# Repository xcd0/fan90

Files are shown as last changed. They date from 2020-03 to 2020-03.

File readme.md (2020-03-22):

# one hand keyboard fan

片手用キーボードです。G13のような用途を想定しています。  
左手で使うことを想定していますが、右手でも使えるようにPCBは作っています。  
流行りのミニマムなキーボードとは反対方向のマキシマムな方向のキーボードです。  
両手で使うことを想定していませんが、両面対応しているので2つ用意すれば可能です。  

初めての自作キーボードなので楽しみなのと不安なのが混在しています\_(:3 」∠ )\_
あくまで初めてつくる自作キーボードであるため、当然ながら動かない可能性が高いです。

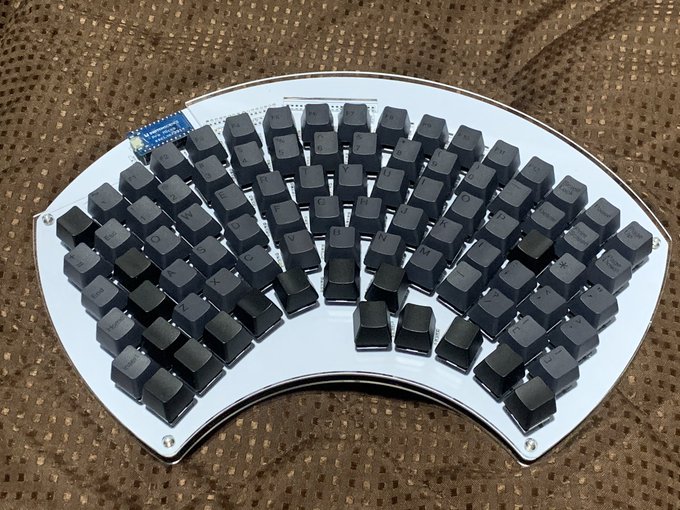
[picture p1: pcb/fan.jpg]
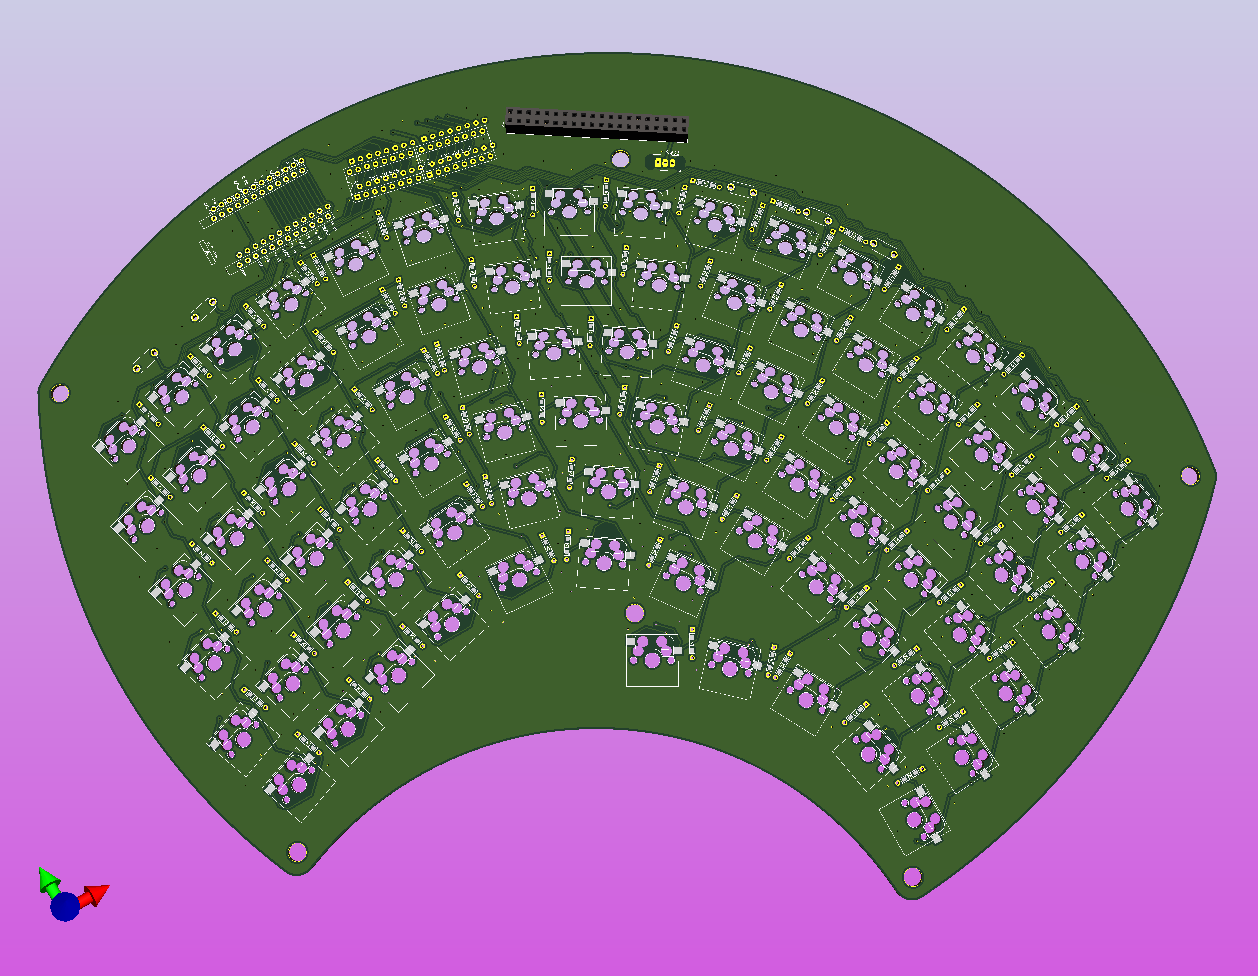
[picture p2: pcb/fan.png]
 
<details>
<summary>開発経緯</summary>

## キーボード割ろうとしたら曲がった
* ありものは素晴らしい、でも自分で作ってみたい。よし、初めてのキーボード自作だ！PCBから作るぞ\\('ω')/
* 今使ってるhelixよい。でもErgodox的な縦のずれがあるキーボードもよさそう。そういうの作ろう...
* 左右分割型のキーボード良い。割りたい！でも左右の通信とかどうやってるんだろう...ちゃんと作れるかな...
* とりあえずキーを並べてみる。小指とか根元に近く配置しよう...
* 見た目汚いな...とりあえずきれいに並べてみるか...あれ、なんか曲がってきた...
* あれこれ片手でフルキーボードいけるんじゃ...

という感じでした\_(:3 」∠ )\_  
つまりキーボードを割ろうとしたが、  
筋力が足りなかったため（左右に分割したときの左右間の通信を電源(VCC,GND)と信号線の3本でどうやって通信してるのかわからなかったので）、  
割れずに曲がってしまった。  
次作るときは割りたい。  
名前は見た目がうちわのようになったため。  もちろん余った基板は重めの団扇として使うことができる。
鍋敷きにしてもよい。
</details>

<details>
<summary>構想</summary>

### コンセプト
以下で東西南北を言うときは、左手で中指の方向を北とした場合の手のひらからの方向を指します。

* 片手でたくさんのキーを使える。
	* フルキーボード相当のキーを使えるものとする。
		* 現状6x15のマトリクスで87キーを配置。
		* 残り３キーはあまり使わない用途向けにリセットスイッチ部品で配置。

* 片手で使いやすい。
	* 指毎の特徴に合わせて配置する。  
		例えば
		* 親指はゲームのコントローラーで多用されるように本来非常に性能が良い。  
		しかしキーボードを使う上で親指を生かすのは難しい。  
		Twitterの投票によると親指に複数のキーを割り当てているときに使っているキーの数はせいぜい4キーらしい。  
		このキーボードでは多めに5キーを割り当てる。
		* 人差し指は性能が良くQWERTYでもほかの指より多いキーを担当する。  
		このキーボードでも人差し指の担当は多くする。
		* 中指は人差し指と同じくらいのせいのがある。中指にも多めのキーを割り当てる。
		* 薬指は中指と一緒に動かないと性能が良くないので、キーボードではあまり性能を発揮できない。
		ただし、北西方向は強く、北西方向に関しては小指より適している。。
		* 小指は短いので、北西方向の移動は難しい。  
		しかし西方向、南西方向はそこそこ性能が良い。
	* 指に合わせてキーを配置する。
		* 変則的な配置なので指１本に対して割り当てられたキーの数は様々。
			* 現状小指20、薬指15、中指12、人差し指31、親指5キー。人差し指と小指は無駄キーを含む。足しても90にはならない。
		* 将来的にはキーを立体的に配置するのもよいが、現状は平面に配置。
	* 指は伸ばした状態のほうが押しやすく、キーを押し分けやすい。
		* 指の根本に近いキーよりも指を伸ばしたときに押すキーのほうが押しやすい。
		* 指の根元に近いキーを減らし、指を伸ばしたときに押すキーを増やす。
	* レイヤーは極力つかわない。
		* シフトキーのように押しながら操作することは片手だと難しい。

* すべてのキーを常に使うキーにはせず、使う用途に合わせてカスタマイズできるよう、無駄にキーを配置する。

### 実現方法

* 以下の2点からキーを扇状に配置する。
	* 小指の性能を発揮できるように小指のキーは手首側に寄せる。
	* 伸ばした状態で使える人差し指、中指のキーを増やす。
* 列方向には揃えず、行方向にはそろえる。
* 無駄にキーを小指の西側、人差し指の東側、すべての指の北側に配置する。つまり一回り大きくする。

### 将来的にやりたいこと

* QMKを使わずに作る。(現状使う)
* C以外の言語で作る。(現状C言語)
* マイコンを複数種類使えるようにする。(現状むずかしい)
* raspberry pi zeroと画面を搭載して、それ単体でPCとして動作させ多機能にする。(現状ソケットのみ用意)
* ケースを3Dプリンターなどでつくる。
* キーを立体的に配置する。

</details>

<details>
<summary>設計</summary>

## PCB設計

kicadを使って設計した。

回路は6x15のマトリクス。column方向からスキャンし、rowを検出する。  
column方向のスキャンは床に転がっていたSN74HC595を使う。  
シフトレジスタを使えば簡単にスキャンできそう。  
これで信号線数を15-5で10本減らせることになる。  
pro microはデジタルIOピンが14本、デジタルとしても使えるアナログIOピンが4本なので、
最大18本をデジタルIOとして使うことができる。
6本をrowのデジタル入力に、5本をシフトレジスタへのデジタル出力に、
2本をリセットスイッチに使用することにした。
配置は特にこだわりなく並べた。このせいで後々苦労するかもしれないがまあ初めてなので良しとする。

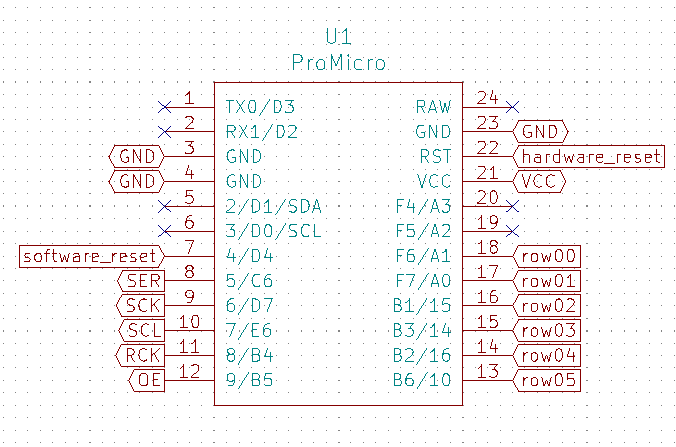
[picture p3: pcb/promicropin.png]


## アクリルケース設計

* ケースもとりあえずアクリルで作ることにした。
* ケースもDXFで入稿できるみたいなのでkicadでそのまま作った。
	* SVGでもよさそうだがそもそもSVGで線幅を狭くするとinkscapeやchromeで表示したとき線が描画されない問題があった。
* アクリルは[工房Emerge+](https://www.emergeplus.jp/laser-cutting-service/)を使ってみることにした。
	* elecrowはウェブサイトの調子が良くないのか、そもそもサービス中止中なのか、  
	https://twitter.com/xcd0/status/1233658167684296704  
	のようにfalseとなっていた。
	* 遊舎工房は、キーボードのサイズが大きいので元のアクリル板が最低でもA3より大きな必要があり、  
	A5,A4,450 X 300と、450x300以外の選択肢がなく、このサイズでも2枚発注する必要がある。  
	そして150x300程度の余白ができてしまう。
	* Emarge+は600x300に対応しており、これだと１枚に収まる。なのでここにしてみた。
	* 遊舎工房とEmerge+はillustratorありきの体制で、すごくストレスフルであった。
	* inkscapeは線幅の問題で使えず、外形と内形を色を変えるとかレイヤーを変えるとか言った操作はillustratorがないと難しいというか不可能な作業であった。
	* 今回５個ほどソフトを試したが、どれも満たせずあきらめてillustratorの7日間仕様版を使った。
	* 次回はaiやsvgではなくDXFで入稿したい。
	* elecrow復活してほしい... ← 復活してた
* データ蹴られるかと思ったがとりあえず通った。
* DXFもレイヤー分けていればよいらしい。

</details>

<details>
<summary>作成</summary>

## はんだ付け

[キースイッチを手軽に交換できる Kailh PCBソケット](https://talpkeyboard.stores.jp/items/5e02c5405b120c792616bcf9)
とダイオードをちまちまつけていく。

ダイオードの向きは今のシルクだと上向きになっているが、
本当は下向きが良い。
上向きだと正論理でキースキャンをする形になる。
それでいいと思っていたが、Pro Microは入力端子の内部抵抗がどうもプルアップにしかできないみたい。
今回はもうダイオードをつけてしまったのでPro Microの入力端子に10kΩの抵抗をつけてプルダウンした。
現状のプログラムはプルダウンした回路を前提にしている。
もし誰か同じものを作りたい人がいたら、回路を修正して内蔵プルアップ抵抗を使う負論理のキースキャンにプログラムを変更する方がよい。

ソケットは向きを考えて穴にはめていく。
はめた状態だとフットプリントが完全に隠れてしまうので、はんだを適当につけたら問題ない。
と思いきや、そうでもなくて、フットプリントとソケットが浮いていたりする...
めちゃもりもりはんだを盛った。

フットプリントを少し大きくした方が良いなとわかった。

## 組み立て

構造は簡単なので特に迷うことはないはず。

## プログラム作成

プログラムは適当にさっと作った。
[ここ](https://docs.qmk.fm/#/ja/custom_matrix)を参考にmatrix.cを追加して、matrix.cにシフトレジスタでキースキャンするプログラムを書いた。

上にも書いたが現状正論理で書いているので新しく作るときは負論理にしたほうがよい。

</details>

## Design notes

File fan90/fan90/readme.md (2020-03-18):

# fan90

* Pro Micro

| ピン | 名前 | 説明 | io  |
| ---  | --- | --- | --- |
| 1 | TX0/D3 | - | - |
| 2 | RX1/D2 | - | - |
| 3 | GND | GND | - |
| 4 | GND | GND | - |
| 5 | D2/ | - | - |
| 6 | D3/ | - | - |
| 7 | D4/ | software reset | i |
| 8 | D5/ | SER | o |
| 9 | D6/ | SCK | o |
| 10 | D7/ | SCL | o |
| 11 | D8/ | RCK | o |
| 12 | D9/ | OE | o |
| 13 | B6/10/D10  | row05 | i |
| 14 | B2/16/MOSI | row04 | i |
| 15 | B3/14/MISO | row03 | i |
| 16 | B1/15/SCK  | row02 | i |
| 17 | F7/A0 | row01 | i |
| 18 | F6/A1 | row00 | i |
| 19 | F5/A2 | - | - |
| 20 | F4/A3 | - | - |
| 21 | VCC | VCC | - |
| 22 | RESET | hardware reset | i |
| 23 | GND | GND | - |
| 24 | VCC | - | - |

* SN74HC595N

| ピン | 名前 | 入出力 | 説明 |
| --- | --- | --- | --- |
| 8 | GND | -– | グラウンド |
| 10 | SRCLR | 入力 | シフトレジスタのクリア |
| 11 | SRCLK | 入力 | シフトレジスタのクロック信号 |
| 12 | RCLK | 入力 | ストレージレジスタのクロック信号 |
| 13 | OE | 入力 | 出力の有効化 |
| 14 | SER | 入力 | シリアル入力 |
| 16 | Vcc | - | –電源 |
| 15,1〜7 | QA、QB〜QH | 出力 | パラレル出力 |
| 9 | QH’ | 出力 | シフトレジスタの最上位ビットの状態を常に出力 |

##

fan90

A short description of the keyboard/project

* Keyboard Maintainer: [xcd0](https://github.com/yourusername)
* Hardware Supported: The PCBs, controllers supported
* Hardware Availability: Links to where you can find this hardware

Make example for this keyboard (after setting up your build environment):

    make fan90:default

See the [build environment setup](https://docs.qmk.fm/#/getting_started_build_tools) and the [make instructions](https://docs.qmk.fm/#/getting_started_make_guide) for more information. Brand new to QMK? Start with our [Complete Newbs Guide](https://docs.qmk.fm/#/newbs).

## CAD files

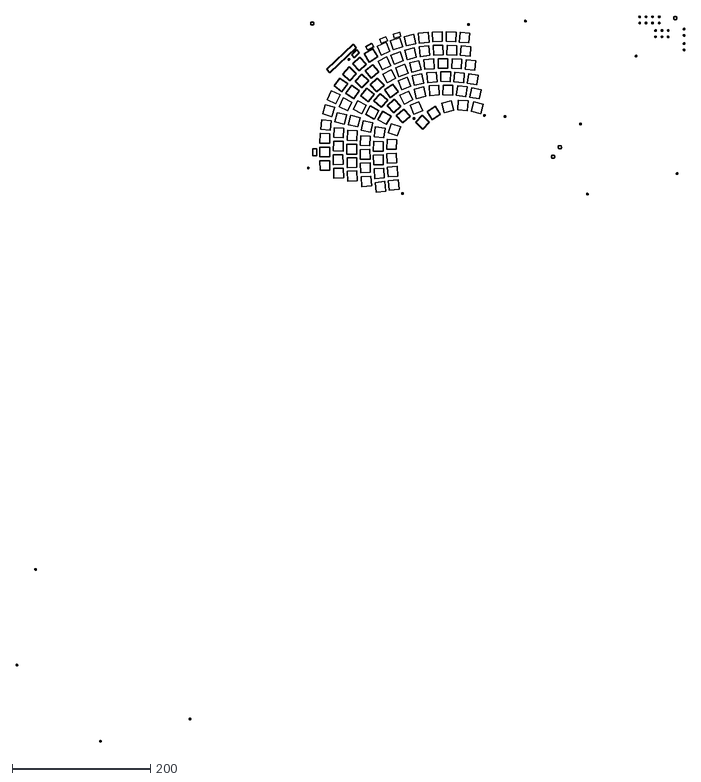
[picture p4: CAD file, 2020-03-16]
pcb/gbr/fan_1.24_300x600_inner.dxf
968.6 x 1051.5

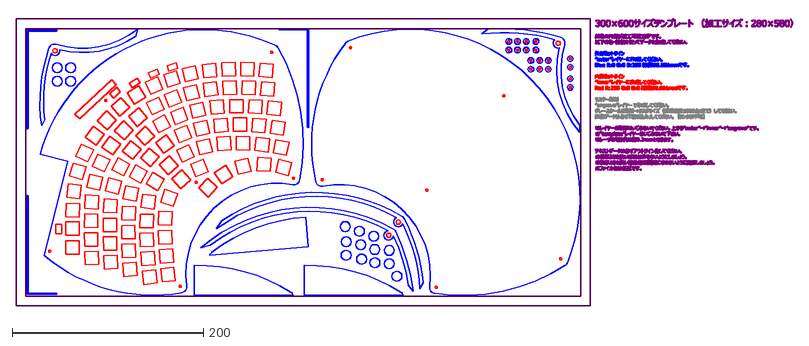
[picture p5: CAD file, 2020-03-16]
pcb/gbr/fan_1.25_300x600.dxf
811.8 x 303.0

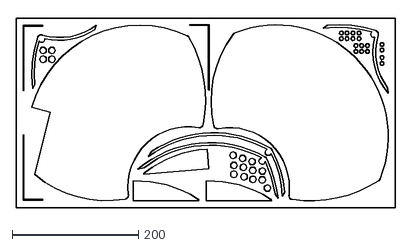
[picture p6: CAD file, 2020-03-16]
pcb/gbr/fan_1.24_300x600_outer.dxf
603.2 x 303.0

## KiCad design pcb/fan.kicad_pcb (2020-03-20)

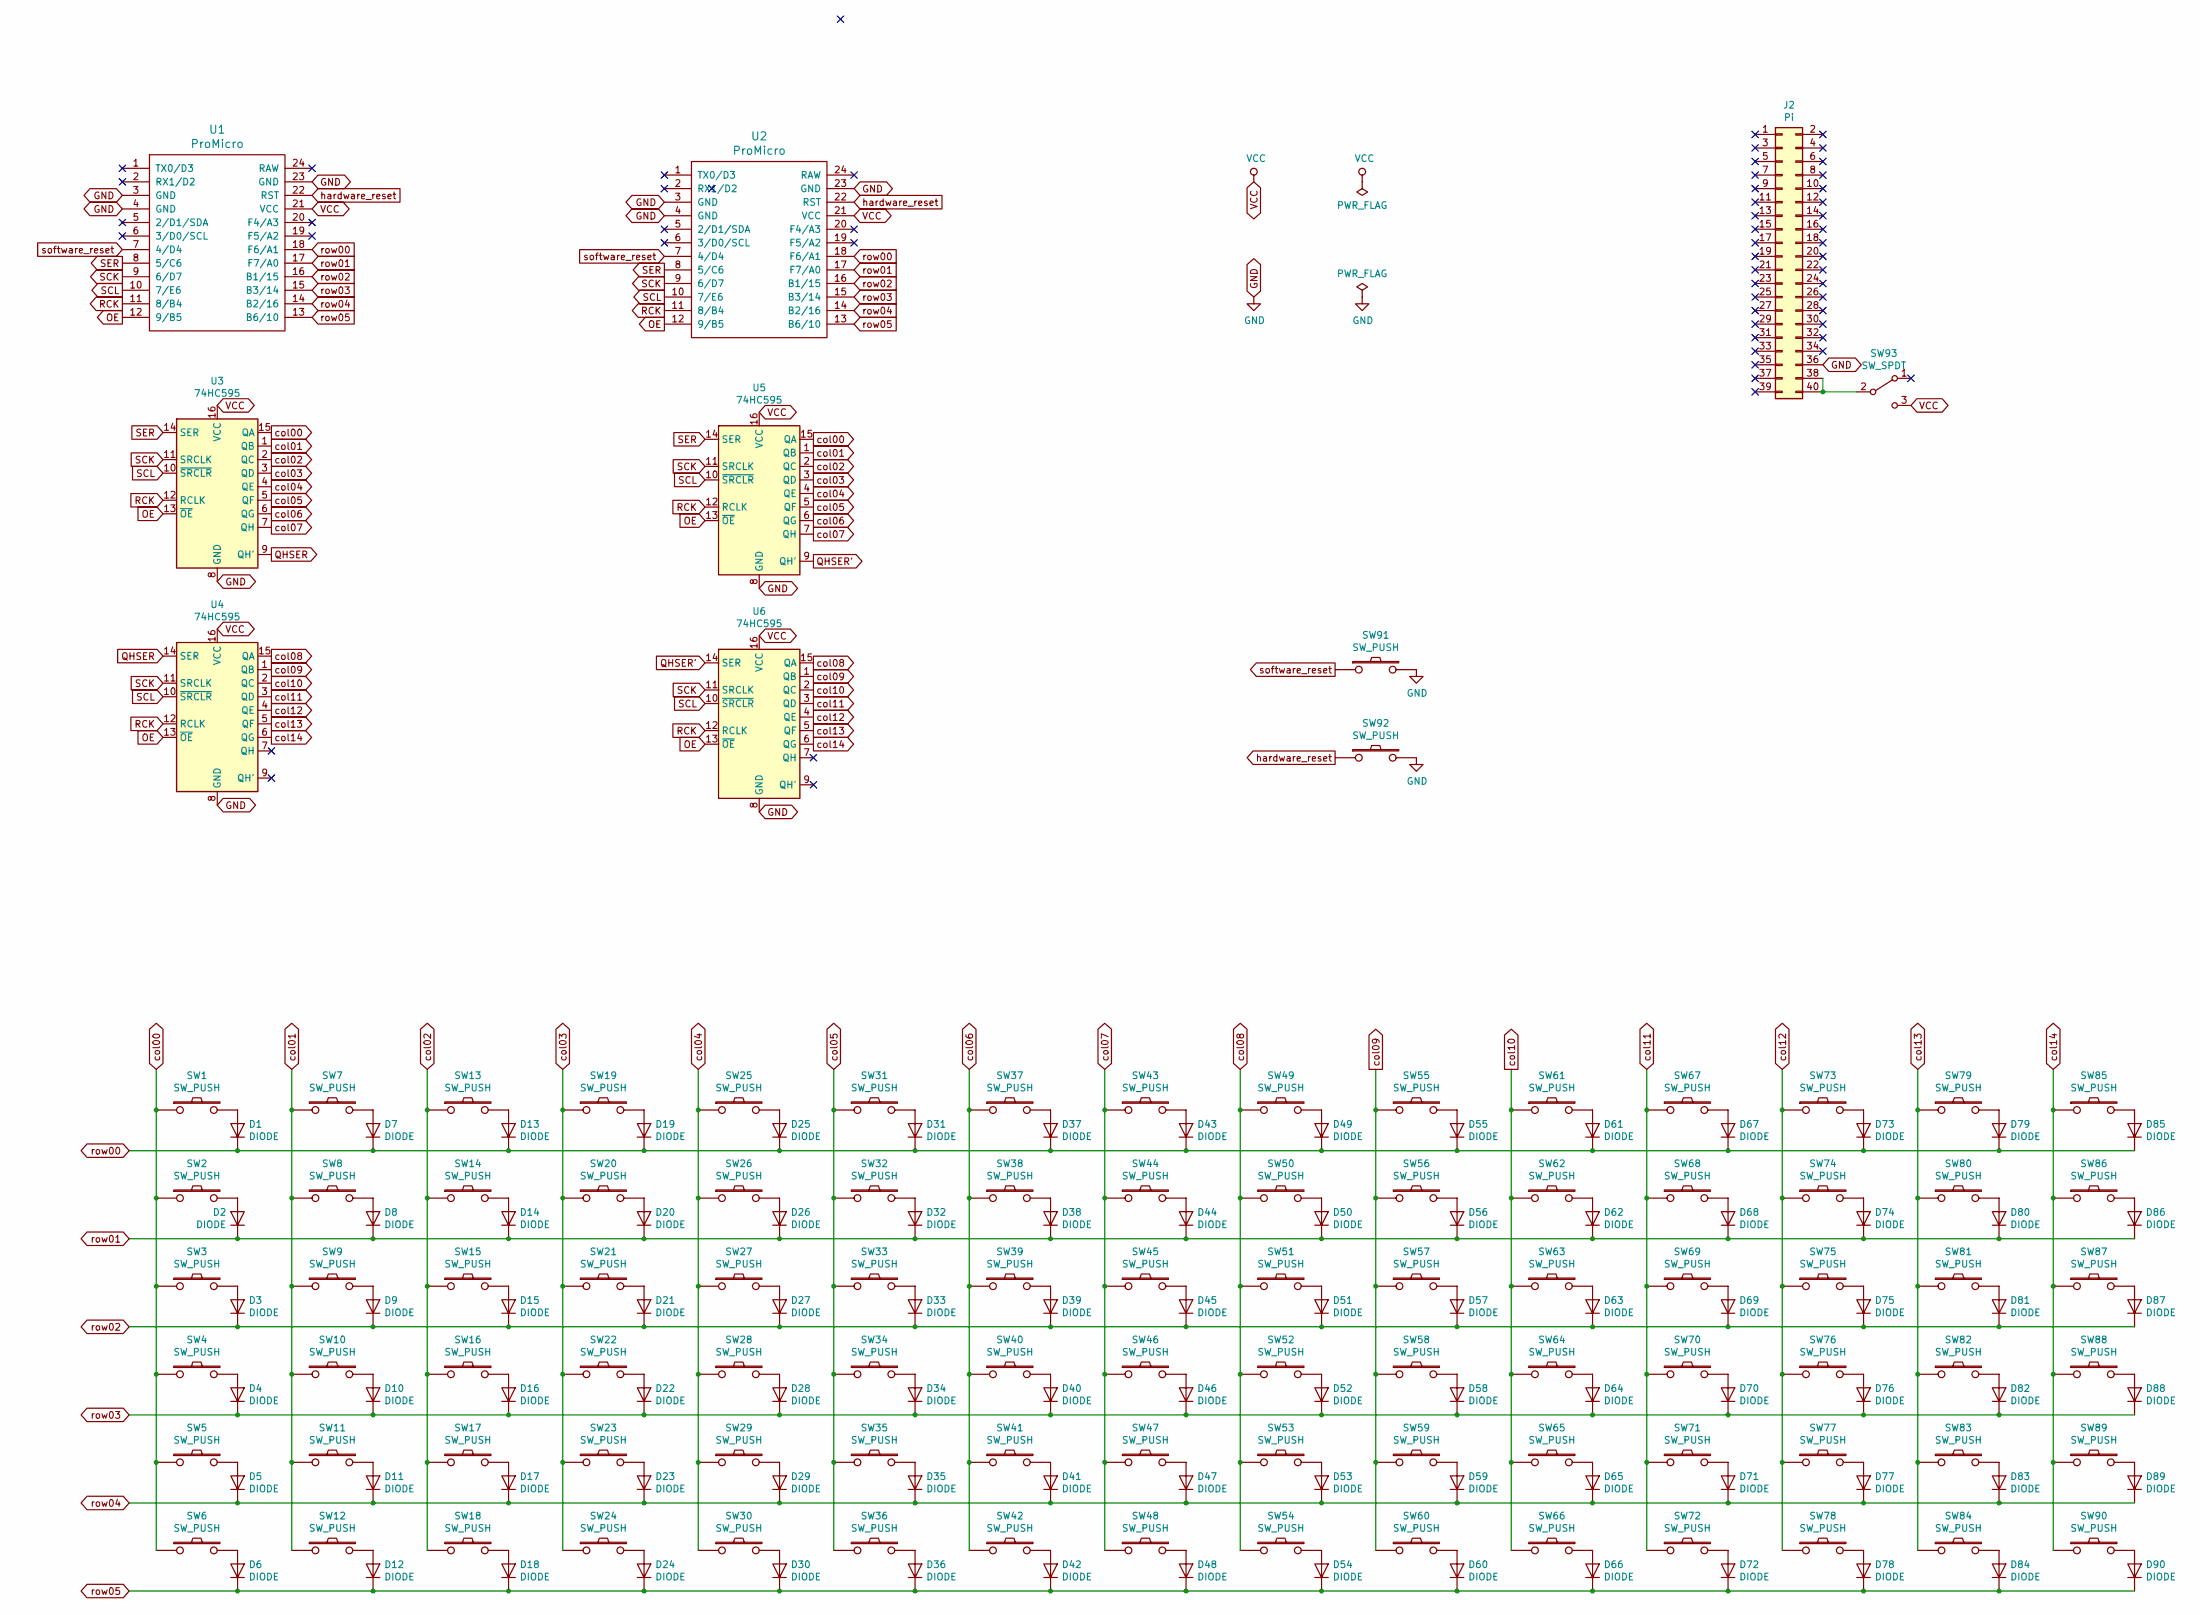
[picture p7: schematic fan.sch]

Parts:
D1, D2, D3, D4, D5, D6, D7, D8, D9, D10, D11, D12, D13, D14, D15, D16, D17, D18, D19, D20, D21, D22, D23, D24, D25, D26, D27, D28, D29, D30, D31, D32, D33, D34, D35, D36, D37, D38, D39, D40, D41, D42, D43, D44, D45, D46, D47, D48, D49, D50, D51, D52, D53, D54, D55, D56, D57, D58, D59, D60, D61, D62, D63, D64, D65, D66, D67, D68, D69, D70, D71, D72, D73, D74, D75, D76, D77, D78, D79, D80, D81, D82, D83, D84, D85, D86, D87, D88, D89, D90: DIODE; D3_TH_SMD
J2: Pi; PinSocket_2x20_P2.54mm_Vertical
SW1, SW2, SW3, SW4, SW5, SW6, SW7, SW8, SW9, SW10, SW11, SW12, SW13, SW14, SW15, SW16, SW17, SW18, SW19, SW20, SW21, SW22, SW23, SW24, SW25, SW26, SW27, SW28, SW29, SW30, SW31, SW32, SW33, SW34, SW35, SW36, SW37, SW38, SW39, SW40, SW41, SW42, SW43, SW44, SW45, SW46, SW47, SW48, SW51, SW52, SW53, SW54, SW56, SW57, SW58, SW59, SW60, SW61, SW62, SW63, SW64, SW65, SW66, SW67, SW68, SW69, SW70, SW71, SW72, SW73, SW74, SW75, SW76, SW77, SW78, SW79, SW80, SW81, SW82, SW83, SW84, SW85, SW86, SW87, SW88, SW89, SW90: SW_PUSH; CherryMX_Hotswap
SW49, SW50, SW55, SW91, SW92: SW_PUSH; ResetSW
SW93: SW_SPDT; SW_Slide_1P2T_CK_OS102011MS2Q
U1, U2: ProMicro; ProMicro_v3.6
U3, U4, U5, U6: 74HC595; SN74HC595_DIP-16_W7.62mm_Socket_2

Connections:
GND: J2.36, SW91.2, SW92.2, U1.3 (GND), U1.4 (GND), U1.23 (GND), U2.3 (GND), U2.4 (GND), U2.23 (GND), U3.8 (GND), U4.8 (GND), U5.8 (GND), U6.8 (GND)
unnamed: D1.2 (A), SW1.2
unnamed: D2.2 (A), SW2.2
unnamed: D3.2 (A), SW3.2
unnamed: D4.2 (A), SW4.2
unnamed: D5.2 (A), SW5.2
unnamed: D6.2 (A), SW6.2
unnamed: D7.2 (A), SW7.2
unnamed: D8.2 (A), SW8.2
unnamed: D9.2 (A), SW9.2
unnamed: D10.2 (A), SW10.2
unnamed: D11.2 (A), SW11.2
unnamed: D12.2 (A), SW12.2
unnamed: D13.2 (A), SW13.2
unnamed: D14.2 (A), SW14.2
unnamed: D15.2 (A), SW15.2
unnamed: D16.2 (A), SW16.2
unnamed: D17.2 (A), SW17.2
unnamed: D18.2 (A), SW18.2
unnamed: D19.2 (A), SW19.2
unnamed: D20.2 (A), SW20.2
unnamed: D21.2 (A), SW21.2
unnamed: D22.2 (A), SW22.2
unnamed: D23.2 (A), SW23.2
unnamed: D24.2 (A), SW24.2
unnamed: D25.2 (A), SW25.2
unnamed: D26.2 (A), SW26.2
unnamed: D27.2 (A), SW27.2
unnamed: D28.2 (A), SW28.2
unnamed: D29.2 (A), SW29.2
unnamed: D30.2 (A), SW30.2
unnamed: D31.2 (A), SW31.2
unnamed: D32.2 (A), SW32.2
unnamed: D33.2 (A), SW33.2
unnamed: D34.2 (A), SW34.2
unnamed: D35.2 (A), SW35.2
unnamed: D36.2 (A), SW36.2
unnamed: D37.2 (A), SW37.2
unnamed: D38.2 (A), SW38.2
unnamed: D39.2 (A), SW39.2
unnamed: D40.2 (A), SW40.2
unnamed: D41.2 (A), SW41.2
unnamed: D42.2 (A), SW42.2
unnamed: D43.2 (A), SW43.2
unnamed: D44.2 (A), SW44.2
unnamed: D45.2 (A), SW45.2
unnamed: D46.2 (A), SW46.2
unnamed: D47.2 (A), SW47.2
unnamed: D48.2 (A), SW48.2
unnamed: D49.2 (A), SW49.2
unnamed: D50.2 (A), SW50.2
unnamed: D51.2 (A), SW51.2
unnamed: D52.2 (A), SW52.2
unnamed: D53.2 (A), SW53.2
unnamed: D54.2 (A), SW54.2
unnamed: D55.2 (A), SW55.2
unnamed: D56.2 (A), SW56.2
unnamed: D57.2 (A), SW57.2
unnamed: D58.2 (A), SW58.2
unnamed: D59.2 (A), SW59.2
unnamed: D60.2 (A), SW60.2
unnamed: D61.2 (A), SW61.2
unnamed: D62.2 (A), SW62.2
unnamed: D63.2 (A), SW63.2
unnamed: D64.2 (A), SW64.2
unnamed: D65.2 (A), SW65.2
unnamed: D66.2 (A), SW66.2
unnamed: D67.2 (A), SW67.2
unnamed: D68.2 (A), SW68.2
unnamed: D69.2 (A), SW69.2
unnamed: D70.2 (A), SW70.2
unnamed: D71.2 (A), SW71.2
unnamed: D72.2 (A), SW72.2
unnamed: D73.2 (A), SW73.2
unnamed: D74.2 (A), SW74.2
unnamed: D75.2 (A), SW75.2
unnamed: D76.2 (A), SW76.2
unnamed: D77.2 (A), SW77.2
unnamed: D78.2 (A), SW78.2
unnamed: D79.2 (A), SW79.2
unnamed: D80.2 (A), SW80.2
unnamed: D81.2 (A), SW81.2
unnamed: D82.2 (A), SW82.2
unnamed: D83.2 (A), SW83.2
unnamed: D84.2 (A), SW84.2
unnamed: D85.2 (A), SW85.2
unnamed: D86.2 (A), SW86.2
unnamed: D87.2 (A), SW87.2
unnamed: D88.2 (A), SW88.2
unnamed: D89.2 (A), SW89.2
unnamed: D90.2 (A), SW90.2
unnamed: J2.38, J2.40, SW93.2 (B)
OE: U1.12 (9/B5), U2.12 (9/B5), U3.13 (~OE), U4.13 (~OE), U5.13 (~OE), U6.13 (~OE)
QHSER: U3.9 (QH'), U4.14 (SER)
QHSER': U5.9 (QH'), U6.14 (SER)
RCK: U1.11 (8/B4), U2.11 (8/B4), U3.12 (RCLK), U4.12 (RCLK), U5.12 (RCLK), U6.12 (RCLK)
SCK: U1.9 (6/D7), U2.9 (6/D7), U3.11 (SRCLK), U4.11 (SRCLK), U5.11 (SRCLK), U6.11 (SRCLK)
SCL: U1.10 (7/E6), U2.10 (7/E6), U3.10 (~SRCLR), U4.10 (~SRCLR), U5.10 (~SRCLR), U6.10 (~SRCLR)
SER: U1.8 (5/C6), U2.8 (5/C6), U3.14 (SER), U5.14 (SER)
VCC: SW93.3 (C), U1.21 (VCC), U2.21 (VCC), U3.16 (VCC), U4.16 (VCC), U5.16 (VCC), U6.16 (VCC)
col00: SW1.1, SW2.1, SW3.1, SW4.1, SW5.1, SW6.1, U3.15 (QA), U5.15 (QA)
col01: SW7.1, SW8.1, SW9.1, SW10.1, SW11.1, SW12.1, U3.1 (QB), U5.1 (QB)
col02: SW13.1, SW14.1, SW15.1, SW16.1, SW17.1, SW18.1, U3.2 (QC), U5.2 (QC)
col03: SW19.1, SW20.1, SW21.1, SW22.1, SW23.1, SW24.1, U3.3 (QD), U5.3 (QD)
col04: SW25.1, SW26.1, SW27.1, SW28.1, SW29.1, SW30.1, U3.4 (QE), U5.4 (QE)
col05: SW31.1, SW32.1, SW33.1, SW34.1, SW35.1, SW36.1, U3.5 (QF), U5.5 (QF)
col06: SW37.1, SW38.1, SW39.1, SW40.1, SW41.1, SW42.1, U3.6 (QG), U5.6 (QG)
col07: SW43.1, SW44.1, SW45.1, SW46.1, SW47.1, SW48.1, U3.7 (QH), U5.7 (QH)
col08: SW49.1, SW50.1, SW51.1, SW52.1, SW53.1, SW54.1, U4.15 (QA), U6.15 (QA)
col09: SW55.1, SW56.1, SW57.1, SW58.1, SW59.1, SW60.1, U4.1 (QB), U6.1 (QB)
col10: SW61.1, SW62.1, SW63.1, SW64.1, SW65.1, SW66.1, U4.2 (QC), U6.2 (QC)
col11: SW67.1, SW68.1, SW69.1, SW70.1, SW71.1, SW72.1, U4.3 (QD), U6.3 (QD)
col12: SW73.1, SW74.1, SW75.1, SW76.1, SW77.1, SW78.1, U4.4 (QE), U6.4 (QE)
col13: SW79.1, SW80.1, SW81.1, SW82.1, SW83.1, SW84.1, U4.5 (QF), U6.5 (QF)
col14: SW85.1, SW86.1, SW87.1, SW88.1, SW89.1, SW90.1, U4.6 (QG), U6.6 (QG)
hardware_reset: SW92.1, U1.22 (RST), U2.22 (RST)
row00: D1.1 (K), D7.1 (K), D13.1 (K), D19.1 (K), D25.1 (K), D31.1 (K), D37.1 (K), D43.1 (K), D49.1 (K), D55.1 (K), D61.1 (K), D67.1 (K), D73.1 (K), D79.1 (K), D85.1 (K), U1.18 (F6/A1), U2.18 (F6/A1)
row01: D2.1 (K), D8.1 (K), D14.1 (K), D20.1 (K), D26.1 (K), D32.1 (K), D38.1 (K), D44.1 (K), D50.1 (K), D56.1 (K), D62.1 (K), D68.1 (K), D74.1 (K), D80.1 (K), D86.1 (K), U1.17 (F7/A0), U2.17 (F7/A0)
row02: D3.1 (K), D9.1 (K), D15.1 (K), D21.1 (K), D27.1 (K), D33.1 (K), D39.1 (K), D45.1 (K), D51.1 (K), D57.1 (K), D63.1 (K), D69.1 (K), D75.1 (K), D81.1 (K), D87.1 (K), U1.16 (B1/15), U2.16 (B1/15)
row03: D4.1 (K), D10.1 (K), D16.1 (K), D22.1 (K), D28.1 (K), D34.1 (K), D40.1 (K), D46.1 (K), D52.1 (K), D58.1 (K), D64.1 (K), D70.1 (K), D76.1 (K), D82.1 (K), D88.1 (K), U1.15 (B3/14), U2.15 (B3/14)
row04: D5.1 (K), D11.1 (K), D17.1 (K), D23.1 (K), D29.1 (K), D35.1 (K), D41.1 (K), D47.1 (K), D53.1 (K), D59.1 (K), D65.1 (K), D71.1 (K), D77.1 (K), D83.1 (K), D89.1 (K), U1.14 (B2/16), U2.14 (B2/16)
row05: D6.1 (K), D12.1 (K), D18.1 (K), D24.1 (K), D30.1 (K), D36.1 (K), D42.1 (K), D48.1 (K), D54.1 (K), D60.1 (K), D66.1 (K), D72.1 (K), D78.1 (K), D84.1 (K), D90.1 (K), U1.13 (B6/10), U2.13 (B6/10)
software_reset: SW91.1, U1.7 (4/D4), U2.7 (4/D4)

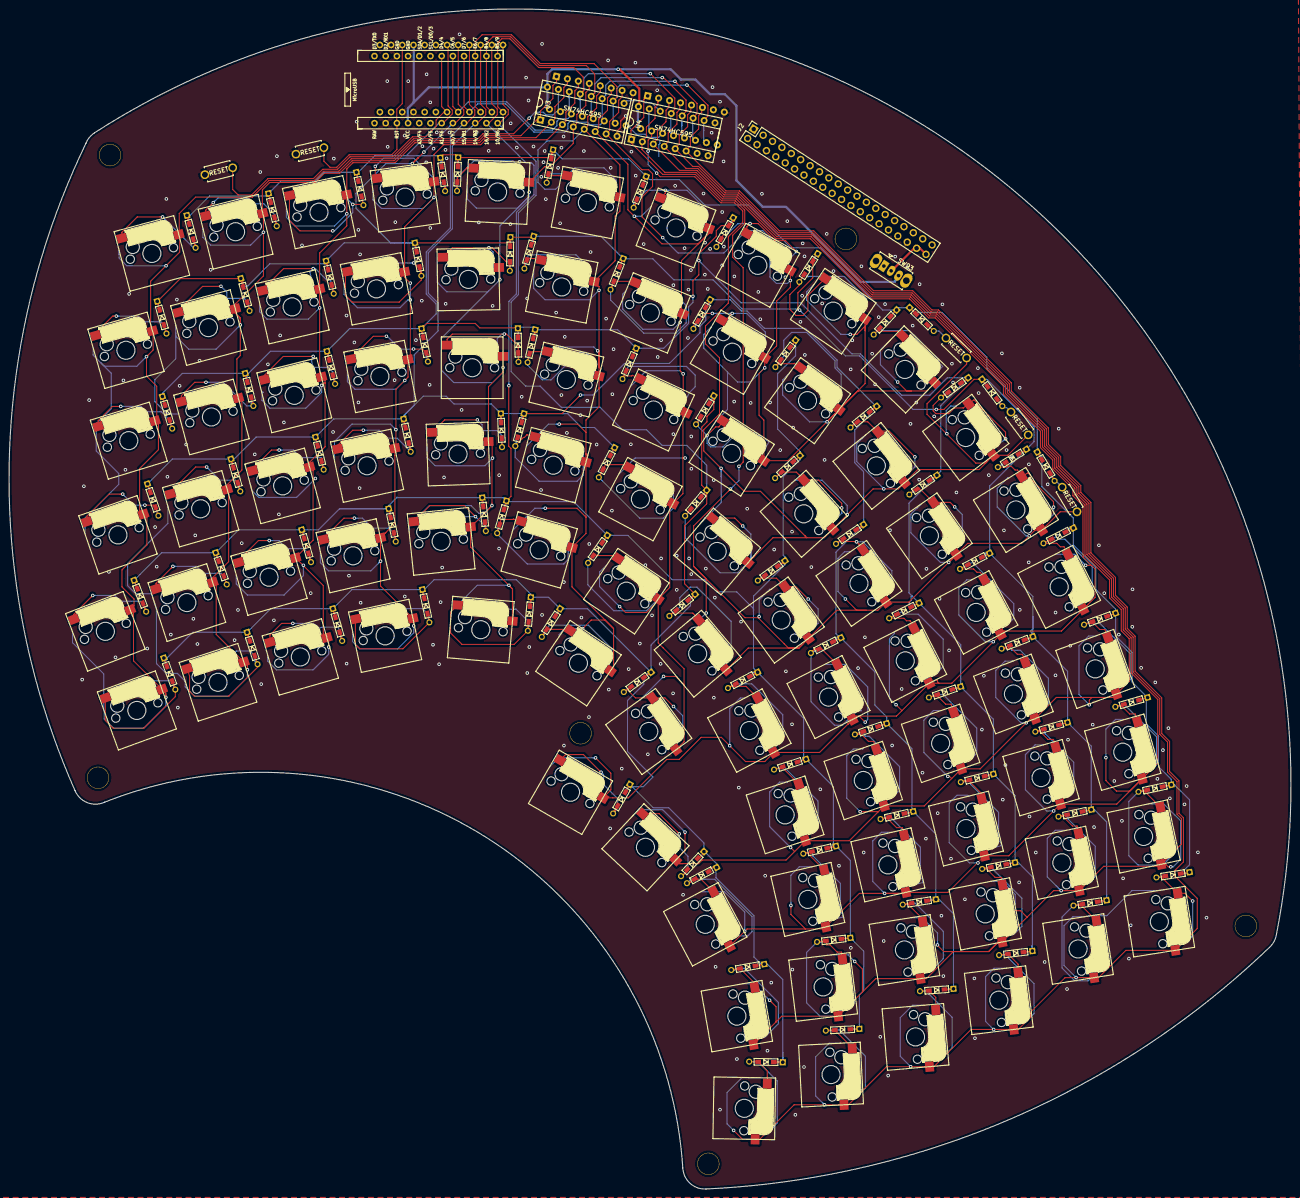
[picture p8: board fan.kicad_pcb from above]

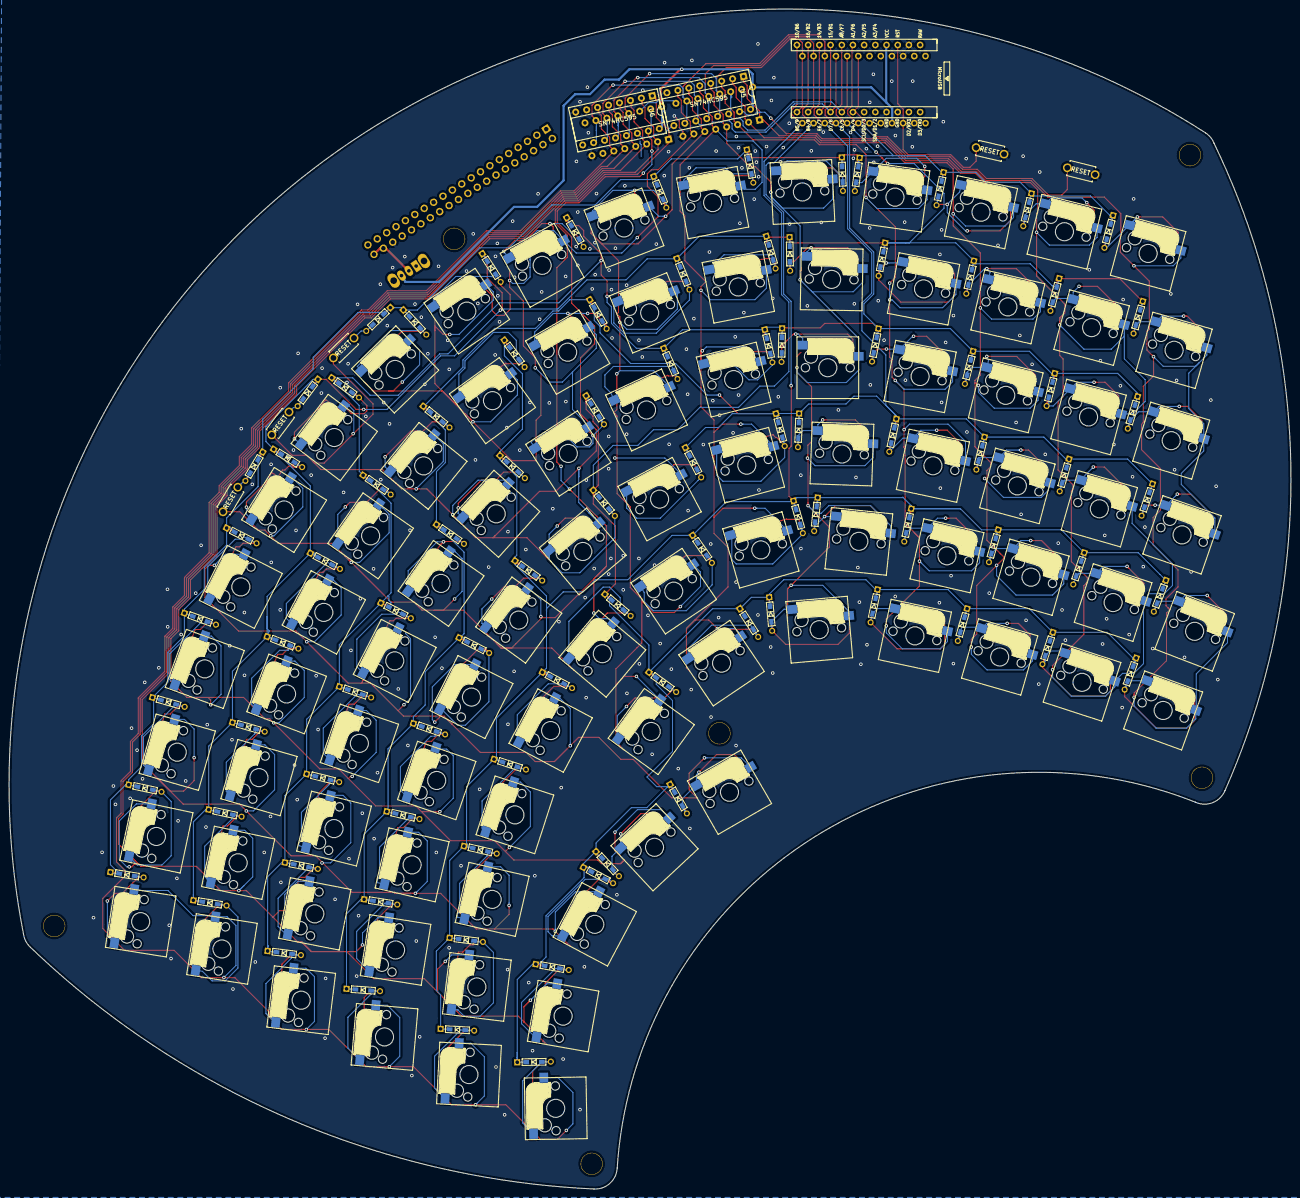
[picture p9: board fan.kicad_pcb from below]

Board: 2 copper layers, 290.9 x 267.8 mm, 196 parts (93 on the bottom side), 123 nets.

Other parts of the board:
HOLE1, HOLE2, HOLE3, HOLE4, HOLE5, HOLE6: Val**; HOLE

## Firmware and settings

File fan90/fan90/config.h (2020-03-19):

/*
Copyright 2020 xcd0

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
You should have received a copy of the GNU General Public License
along with this program.  If not, see <http://www.gnu.org/licenses/>.
*/

#pragma once

#include "config_common.h"

/* USB Device descriptor parameter */
#define VENDOR_ID 0xFEED
#define PRODUCT_ID 0x0000
#define DEVICE_VER 0x0001
#define MANUFACTURER xcd0
#define PRODUCT fan90
#define DESCRIPTION A custom keyboard

/* key matrix size */
#define MATRIX_ROWS 6
#define MATRIX_COLS 15

/*
 * Keyboard Matrix Assignments
 *
 * Change this to how you wired your keyboard
 * COLS: AVR pins used for columns, left to right
 * ROWS: AVR pins used for rows, top to bottom
 * DIODE_DIRECTION: COL2ROW = COL = Anode (+), ROW = Cathode (-, marked on diode)
 *                  ROW2COL = ROW = Anode (+), COL = Cathode (-, marked on diode)
 *
 */

#define MATRIX_ROW_PINS { F6, F7, B1, B3, B2, B6 }
#define MATRIX_COL_PINS { }
#define UNUSED_PINS

/* COL2ROW, ROW2COL*/
//#define DIODE_DIRECTION COL2ROW
#define DIODE_DIRECTION CUSTOM_MATRIX

/*
 * Split Keyboard specific options, make sure you have 'SPLIT_KEYBOARD = yes' in your rules.mk, and define SOFT_SERIAL_PIN.
 */
//#define SOFT_SERIAL_PIN D0  // or D1, D2, D3, E6

// #define BACKLIGHT_PIN B7
// #define BACKLIGHT_BREATHING
// #define BACKLIGHT_LEVELS 3

// #define RGB_DI_PIN E2
// #ifdef RGB_DI_PIN
//   #define RGBLED_NUM 16
//   #define RGBLIGHT_HUE_STEP 8
//   #define RGBLIGHT_SAT_STEP 8
//   #define RGBLIGHT_VAL_STEP 8
//   #define RGBLIGHT_LIMIT_VAL 255 /* The maximum brightness level */
//   #define RGBLIGHT_SLEEP  /* If defined, the RGB lighting will be switched off when the host goes to sleep */
// /*== all animations enable ==*/
//   #define RGBLIGHT_ANIMATIONS
// /*== or choose animations ==*/
//   #define RGBLIGHT_EFFECT_BREATHING
//   #define RGBLIGHT_EFFECT_RAINBOW_MOOD
//   #define RGBLIGHT_EFFECT_RAINBOW_SWIRL
//   #define RGBLIGHT_EFFECT_SNAKE
//   #define RGBLIGHT_EFFECT_KNIGHT
//   #define RGBLIGHT_EFFECT_CHRISTMAS
//   #define RGBLIGHT_EFFECT_STATIC_GRADIENT
//   #define RGBLIGHT_EFFECT_RGB_TEST
//   #define RGBLIGHT_EFFECT_ALTERNATING
// /*== customize breathing effect ==*/
//   /*==== (DEFAULT) use fixed table instead of exp() and sin() ====*/
//   #define RGBLIGHT_BREATHE_TABLE_SIZE 256      // 256(default) or 128 or 64
//   /*==== use exp() and sin() ====*/
//   #define RGBLIGHT_EFFECT_BREATHE_CENTER 1.85  // 1 to 2.7
//   #define RGBLIGHT_EFFECT_BREATHE_MAX    255   // 0 to 255
// #endif

/* Debounce reduces chatter (unintended double-presses) - set 0 if debouncing is not needed */
#define DEBOUNCE 5

/* define if matrix has ghost (lacks anti-ghosting diodes) */
//#define MATRIX_HAS_GHOST

/* Mechanical locking support. Use KC_LCAP, KC_LNUM or KC_LSCR instead in keymap */
#define LOCKING_SUPPORT_ENABLE
/* Locking resynchronize hack */
#define LOCKING_RESYNC_ENABLE

/* If defined, GRAVE_ESC will always act as ESC when CTRL is held.
 * This is userful for the Windows task manager shortcut (ctrl+shift+esc).
 */
// #define GRAVE_ESC_CTRL_OVERRIDE

/*
 * Force NKRO
 *
 * Force NKRO (nKey Rollover) to be enabled by default, regardless of the saved
 * state in the bootmagic EEPROM settings. (Note that NKRO must be enabled in the
 * makefile for this to work.)
 *
 * If forced on, NKRO can be disabled via magic key (default = LShift+RShift+N)
 * until the next keyboard reset.
 *
 * NKRO may prevent your keystrokes from being detected in the BIOS, but it is
 * fully operational during normal computer usage.
 *
 * For a less heavy-handed approach, enable NKRO via magic key (LShift+RShift+N)
 * or via bootmagic (hold SPACE+N while plugging in the keyboard). Once set by
 * bootmagic, NKRO mode will always be enabled until it is toggled again during a
 * power-up.
 *
 */
#define FORCE_NKRO

/*
 * Magic Key Options
 *
 * Magic keys are hotkey commands that allow control over firmware functions of
 * the keyboard. They are best used in combination with the HID Listen program,
 * found here: https://www.pjrc.com/teensy/hid_listen.html
 *
 * The options below allow the magic key functionality to be changed. This is
 * useful if your keyboard/keypad is missing keys and you want magic key support.
 *
 */

/* key combination for magic key command */
/* defined by default; to change, uncomment and set to the combination you want */
// #define IS_COMMAND() (get_mods() == MOD_MASK_SHIFT)

/* control how magic key switches layers */
//#define MAGIC_KEY_SWITCH_LAYER_WITH_FKEYS  true
//#define MAGIC_KEY_SWITCH_LAYER_WITH_NKEYS  true
//#define MAGIC_KEY_SWITCH_LAYER_WITH_CUSTOM false
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

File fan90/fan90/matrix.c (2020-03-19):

// https://docs.qmk.fm/#/custom_matrix
// https://github.com/qmk/qmk_firmware/blob/ece14278efe5168ef20298984bff4b1d5eb43e4b/quantum/matrix_common.c#L108
// https://synapse.kyoto/glossary/74hc595/page001.html
//
// | 8   | D5/        | SER            | o   |
// | 9   | D6/        | SCK            | o   |
// | 10  | D7/        | SCL            | o   |
// | 11  | D8/        | RCK            | o   |
// | 12  | D9/        | OE             | o   |
//

int row_pins[] = { F6,F7,B1,B3,B2,B6 };
static bool readRowPin(int rowNum ){ return readPin(row_pins[rowNum]); }

static void GPIO_DELAY(){
	// GPIOでシフトレジスタを制御する際に各信号間で遅延を入れたい場合ここに入れる
	//delayMicroseconds( 10 ); // <- 使えるか知らない
}

static void SR_SER_HIGH(){ writePinHigh(D5); GPIO_DELAY(); }                // D5 SER
static void SR_SER_LOW(){ writePinLow(D5); GPIO_DELAY(); }                  // D6 CLR
static void SR_CLEAR(){ writePinLow(D6); GPIO_DELAY(); writePinHigh(D6); GPIO_DELAY();}  // D6 CLR
static void SR_CLOCK(){ writePinLow(D7); GPIO_DELAY(); writePinHigh(D7); GPIO_DELAY();}  // D7 CLK
static void SR_RCLOCK(){ writePinLow(D8); GPIO_DELAY(); writePinHigh(D8); GPIO_DELAY();} // D8 RCK
static void SR_OE_OUTPUT_DISABLE(){ writePinHigh(D9); GPIO_DELAY(); }     // D9 OE
static void SR_OE_OUTPOT_ENABLE(){ writePinLow(D9); GPIO_DELAY(); }     // D9 OE

static void SR_SCAN_COL_SET( int colNum ){
	SR_CLEAR(); // クリア
	bool col[ MATRIX_COLS ] = { false };
	col[colNum] = 1;
	int i = 0;
	for(; i < MATRIX_COLS; i++ ){
		if( col[i] ){
			SR_SER_HIGH();
		} else {
			SR_SER_LOW();
		}
		SR_CLOCK();
	}
	SR_RCLOCK(); // ピンに出力
}

static void matrix_init_custom(void) { // {{{
	// TODO: initialize hardware here

	// initialize matrix state: all keys off
	for (uint8_t i = 0; i < MATRIX_ROWS; i++) {
		raw_matrix[i] = 0;
		matrix[i]     = 0;
	}

	debounce_init(MATRIX_ROWS);

	matrix_init_quantum();

	//setPinInputHigh(pin); // Set pin as input with builtin pull-up resistor
	//setPinOutput(pin); // Set pin as output
	//writePinHigh(pin); // Set pin level as high, assuming it is an output
	//writePinLow(pin); // Set pin level as low, assuming it is an output
	//readPin(pin); // Returns the level of the pin

	int input[7] = {D4,B6,B2,B3,B1,F7,F6};
	int output[5] = {D5,D6,D7,D8,D9};

	for(int i = 1; i <= 7; i++){
		setPinInputHigh(i); // Set pin as input with builtin pull-up resistor
	}
	for(int i = 1; i <= 5; i++){
		setPinOutput(i); // Set pin as output
	}

	// シフトレジスタの設定
	SR_CLEAR();
	SR_OE_OUTPUT_ENABLE(); // 内部で出力を接続する (出力をハイインピーダンス状態にしない)
	writePinHigh(D8); // RCLK


	//writePinHigh(pin); // Set pin level as high, assuming it is an output
	//writePinLow(pin); // Set pin level as low, assuming it is an output
} // }}}

static void read_row( matrix_row_t current_matrix[], uint8_t current_row) {
}

bool matrix_scan_custom(matrix_row_t current_matrix[]) {
	bool matrix_has_changed = false;

	// TODO: add matrix scanning routine here

	//writePinHigh(pin); // Set pin level as high, assuming it is an output
	//writePinLow(pin); // Set pin level as low, assuming it is an output
	//readPin(pin); // Returns the level of the pin

	bool last_row_value = current_matrix;

	for (uint8_t c = 0; c < MATRIX_COLS; c++) {
		SR_SCAN_COL_SET(c); // シフトレジスタでc列だけHIGHにする
		for( int r = 0; r < MATRIX_ROWS; r++ ){
			matrix_row_t last_row_value = current_matrix[r];
			current_matrix[c] = readPin(r);
			matrix_has_changed |= (last_row_value != current_matrix[current_row]);
		}
		raw_matrix[i] = 0;
		matrix[i]     = 0;
	}
	SR_CLEAR();

	return matrix_has_changed;
}

static bool read_cols_on_row(matrix_row_t current_matrix[], uint8_t current_row) {
	matrix_row_t last_row_value = current_matrix[current_row];
	current_matrix[current_row] = 0;

	for (uint8_t col_index = 0; col_index < MATRIX_COLS; col_index++) {
		pin_t pin = direct_pins[current_row][col_index];
		if (pin != NO_PIN) {
			current_matrix[current_row] |= readPin(pin) ? 0 : (MATRIX_ROW_SHIFTER << col_index);
		}
	}

	return (last_row_value != current_matrix[current_row]);
}
static bool read_rows_on_col(matrix_row_t current_matrix[], uint8_t current_col) {
	bool matrix_changed = false;

	// Select col and wait for col selecton to stabilize
	select_col(current_col);
	matrix_io_delay();

	// For each row...
	for (uint8_t row_index = 0; row_index < ROWS_PER_HAND; row_index++) {
		// Store last value of row prior to reading
		matrix_row_t last_row_value = current_matrix[row_index];

		// Check row pin state
		if (readPin(row_pins[row_index]) == 0) {
			// Pin LO, set col bit
			current_matrix[row_index] |= (MATRIX_ROW_SHIFTER << current_col);
		} else {
			// Pin HI, clear col bit
			current_matrix[row_index] &= ~(MATRIX_ROW_SHIFTER << current_col);
		}

		// Determine if the matrix changed state
		if ((last_row_value != current_matrix[row_index]) && !(matrix_changed)) {
			matrix_changed = true;
		}
	}

	// Unselect col
	unselect_col(current_col);

	return matrix_changed;
}

/*
 * pro micro pin
 * | pin | name       | use            | io  |
 * | --- | ---        | ---            | --- |
 * | 1   | TX0/D3     | -              | -   |
 * | 2   | RX1/D2     | -              | -   |
 * | 3   | GND        | GND            | -   |
 * | 4   | GND        | GND            | -   |
 * | 5   | D2/        | -              | -   |
 * | 6   | D3/        | -              | -   |
 * | 7   | D4/        | software reset | i   |
 * | 8   | D5/        | SER            | o   |
 * | 9   | D6/        | SCK            | o   |
 * | 10  | D7/        | SCL            | o   |
 * | 11  | D8/        | RCK            | o   |
 * | 12  | D9/        | OE             | o   |
 * | 13  | B6/10/D10  | row05          | i   |
 * | 14  | B2/16/MOSI | row04          | i   |
 * | 15  | B3/14/MISO | row03          | i   |
 * | 16  | B1/15/SCK  | row02          | i   |
 * | 17  | F7/A0      | row01          | i   |
 * | 18  | F6/A1      | row00          | i   |
 * | 19  | F5/A2      | -              | -   |
 * | 20  | F4/A3      | -              | -   |
 * | 21  | VCC        | VCC            | -   |
 * | 22  | RESET      | hardware reset | i   |
 * | 23  | GND        | GND            | -   |
 * | 24  | VCC        | -              | -   |
 *
 *
 *
 */


/*
 *https://docs.qmk.fm/#/custom_matrix

 matrix_row_t matrix_get_row(uint8_t row) {
// TODO: return the requested row data
}

void matrix_print(void) {
// TODO: use print() to dump the current matrix state to console
}

void matrix_init(void) {
// TODO: initialize hardware and global matrix state here

// Unless hardware debouncing - Init the configured debounce routine
debounce_init(MATRIX_ROWS);

// This *must* be called for correct keyboard behavior
matrix_init_quantum();
}

uint8_t matrix_scan(void) {
bool matrix_has_changed = false;

// TODO: add matrix scanning routine here

// Unless hardware debouncing - use the configured debounce routine
debounce(raw_matrix, matrix, MATRIX_ROWS, changed);

// This *must* be called for correct keyboard behavior
matrix_scan_quantum();

return matrix_has_changed;
}
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

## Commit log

2020-03-16 fan90を切り分けた
2020-03-16 fan90専用のリポジトリにした
    [cfan.dsn, fan-Eco1_User.dxf, fan-Eco2_User.dxf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]
2020-03-19 matrix.c 少し書いた
2020-03-20 うごかない
    [fan.kicad_pcb]
2020-03-20 commit できてなかった_(:3 」∠ )_
2020-03-20 シンボリックリンクを張るbatファイルを追加
2020-03-21 いきづまった
2020-03-21 じわっと進んだ
2020-03-21 うごいた
2020-03-21 とりあえずいったん完成とする。 キーマップはじっくり考える

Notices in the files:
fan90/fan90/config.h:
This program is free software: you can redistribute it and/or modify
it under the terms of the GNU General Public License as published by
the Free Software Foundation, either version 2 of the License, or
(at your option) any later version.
